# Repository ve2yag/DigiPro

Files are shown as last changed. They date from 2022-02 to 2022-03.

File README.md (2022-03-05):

# DigiPro
 Lora APRS digipeater for Arduino/AVR
 
 Atmega 168/328P(B) using internal 8MHz RC oscillator at 3.3 volts.
 
 - Support Lora carrier detect and collision avoiding using persistance and slottime, just like standard APRS
 - Compatible with ASCII packet format [LoRa-APRS-tracker](https://github.com/lora-aprs/LoRa_APRS_Tracker) and binary/AX25 format [sh123/esp32_loraprs](https://github.com/sh123/esp32_loraprs)
 - Digipeat packet in same format received. Digi beaconing and telemetry use the most heard format.
 - Digipeater support WIDEx-x and SSID digipeating for shortest packet.
 - Support ?APRS? and ?APRSS query
 - Support message ACKing, but don't use messaging for now. (remote config?)
 - Support 18650 battery voltage monitoring and sleep mode under 3.5 volts
 - Additional telemetry using DS18B20 and BMP180 for internal/external temperature and pressure.

Digipeater are extremly efficient, current draw is around 10,5ma on receive and 0,5ma when enter sleep mode. Only Lora module are powered and CPU stay in power down mode (few uA) Wake only when incoming packet is ready inside Lora module, also wake each second to check if it time to transmit beacon and telemetry. When all is tuned, I put some Goop glue on feedpoint connection to waterproof them.

Configure radio and digi with project.h file. 

[See schematic and PCB](Board.pdf)

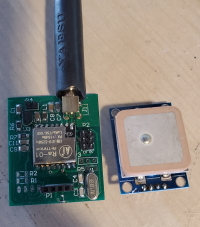
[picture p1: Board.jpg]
Board
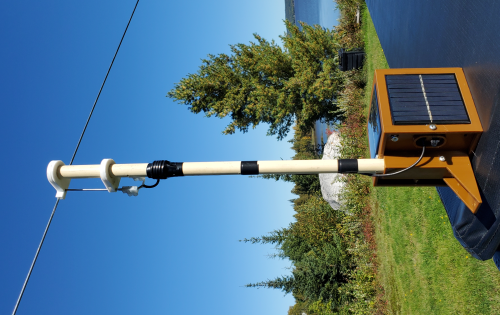
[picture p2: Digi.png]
Digi VA2AIG-4
  

Antenna is 3D printed EDZ, 2x 5/8 wave. 8.1dbi and easy to tune. Antenna is made from 36" stainless tig welding rod, 3/32 inch. Mast is 1/2 water CPVC pipe, coax RG-174/U. Coax coil at feed point is current balun to stabilize antenna pattern and choke current flow back to Lora module.

Enclosure is 3D printed, using Cubesat shape. Solar panel are 80mmx80mm 160ma@5v, 3 sides. (3D model in 3D_enclosure and antenna folder)

VA2AIG-4, Digipeater wide coverage (Have a bug with V2.0) [Map](https://fr.aprs.fi/#!call=a%2FVA2AIG-4&timerange=3600&tail=3600)
VE2YAG-4, Test digipeater, V2.1. Testing now at home, see telemetry.
[Telemetry](https://fr.aprs.fi/telemetry/a/VE2YAG-4) or see on [Map](https://fr.aprs.fi/info/a/VE2YAG-4)

I use also [MicroBeacon_2021](https://github.com/ve2yag/MicroBeacon_2021) as small testing tracker(same PCB) and Lorakiss as Kiss-over-IP Lora modem, hooked to APRX on a raspberry pi to create a dual-port igate with Direwolf.

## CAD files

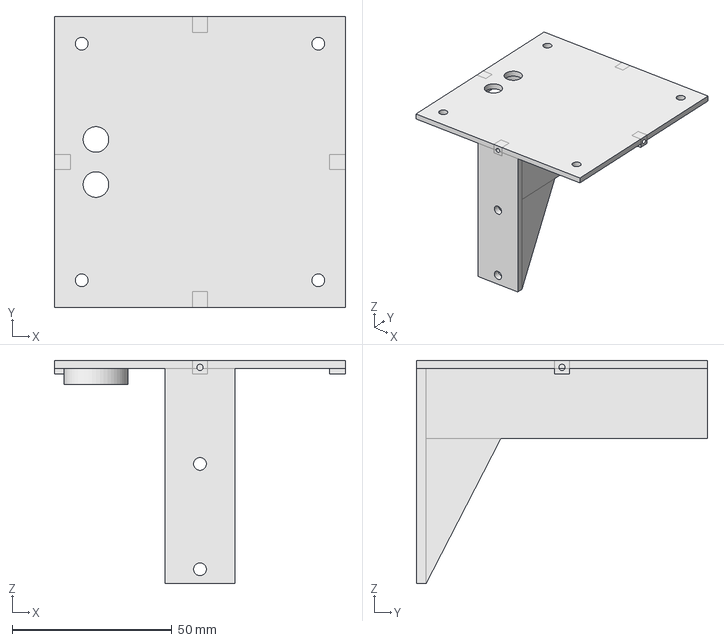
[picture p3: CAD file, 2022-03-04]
3D_enclosure/Base_RB_V1.2.FCStd
91.0 x 91.0 x 69.8 mm

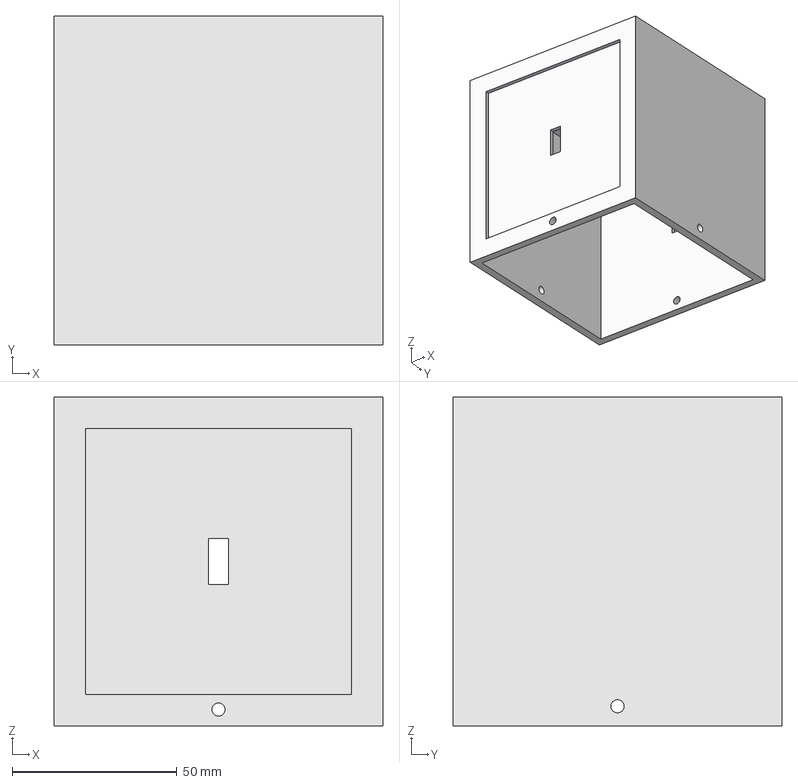
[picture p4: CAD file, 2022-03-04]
3D_enclosure/Cube_RB_V1.1.FCStd
100.0 x 100.0 x 100.0 mm

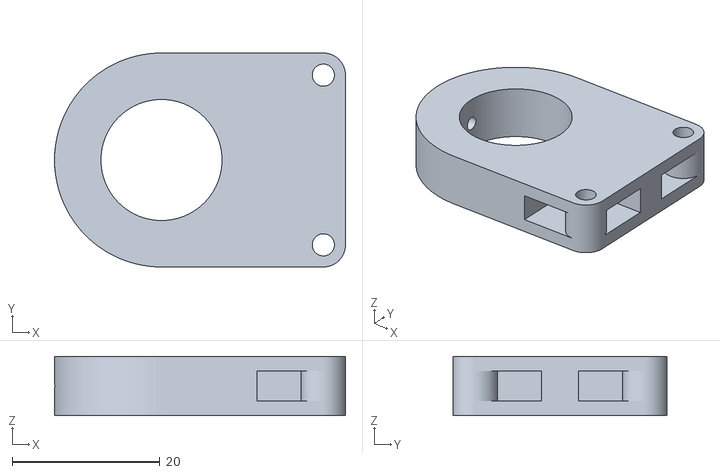
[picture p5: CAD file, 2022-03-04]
antenna/phasing mount-Body.stl
39.4 x 29.0 x 8.00

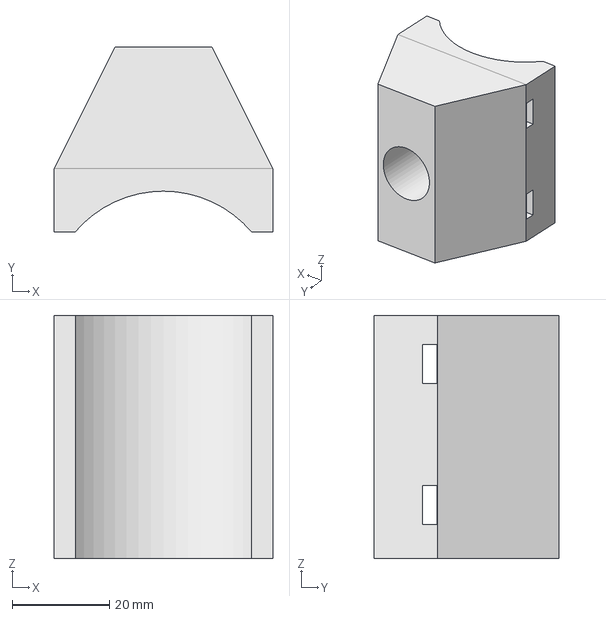
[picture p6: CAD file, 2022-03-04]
antenna/pole mount.FCStd
45.0 x 38.0 x 50.0 mm

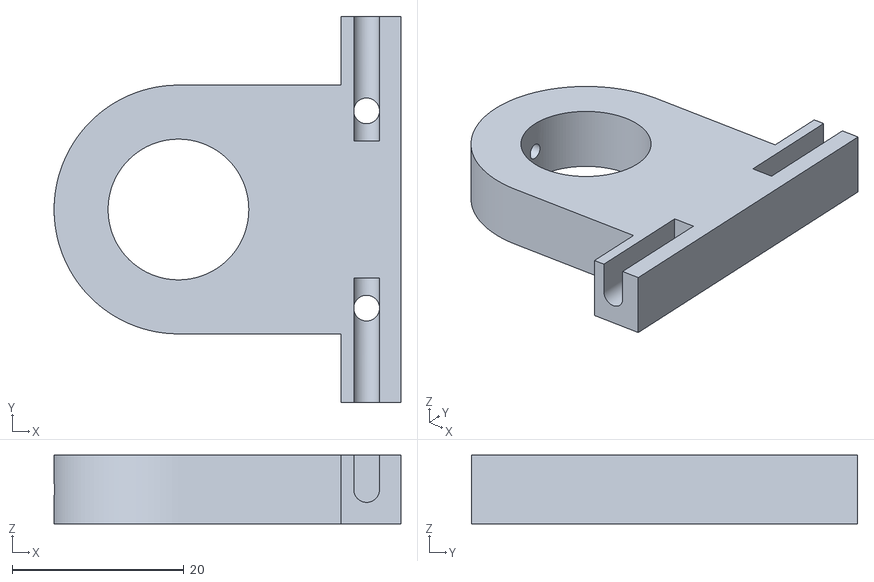
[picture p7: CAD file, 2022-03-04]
antenna/End mount V2-Body.stl
40.4 x 45.0 x 8.00

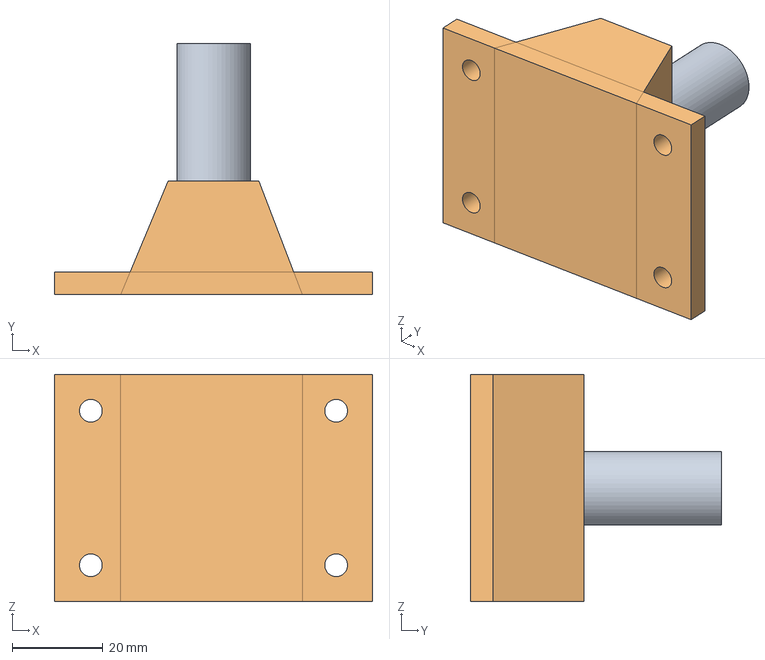
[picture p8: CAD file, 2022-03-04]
antenna/screw mount.FCStd
70.0 x 55.3 x 50.0 mm
hole body

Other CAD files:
3D_enclosure/Cube_RB_V1.1-Body.stl
3D_enclosure/Base_RB_V1.2-Body.stl
antenna/End mount V2.FCStd
antenna/phasing mount.FCStd
antenna/screw mount.stl

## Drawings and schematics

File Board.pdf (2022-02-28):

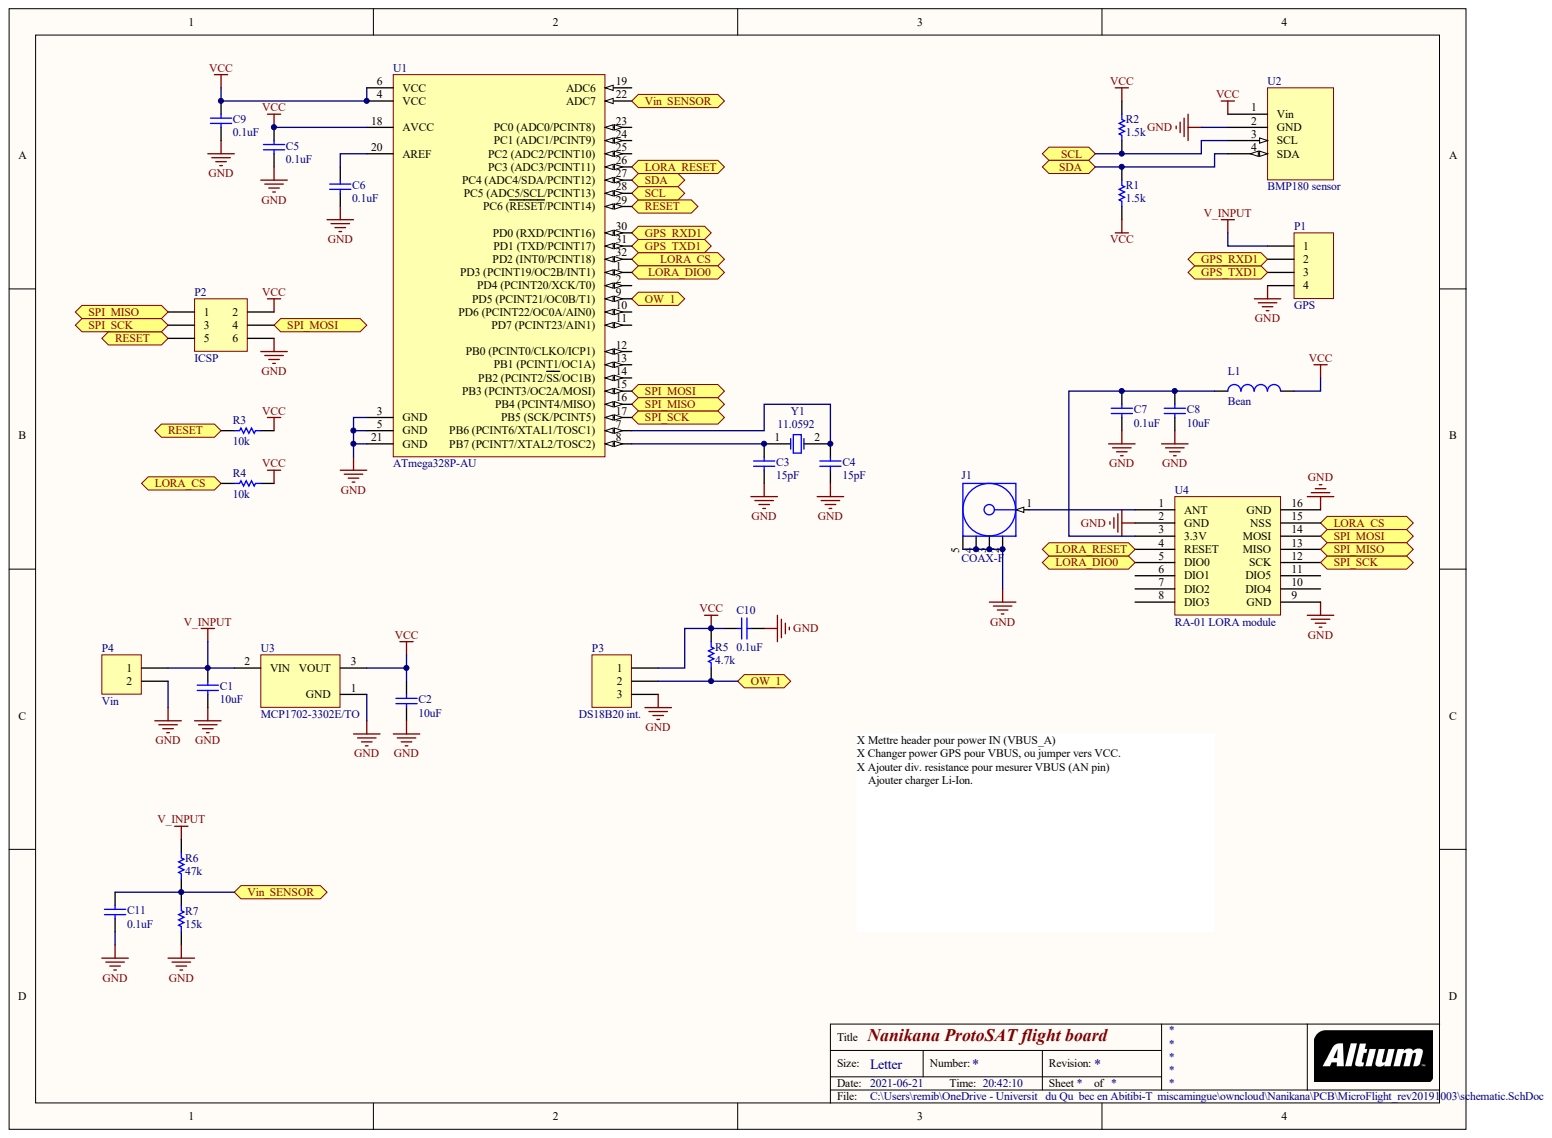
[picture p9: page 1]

X Mettre header pour power IN (VBUS_A)
X Changer power GPS pour VBUS, ou jumper vers VCC.
X Ajouter div. resistance pour mesurer VBUS (AN pin)
Ajouter charger Li-Ion.

Title Nanikana ProtoSAT flight board | * * * * *

Letter Size: | * Number: | * Revision:
Date: 2021-06-21 Time: 20:42:10 | | Sheet * of *

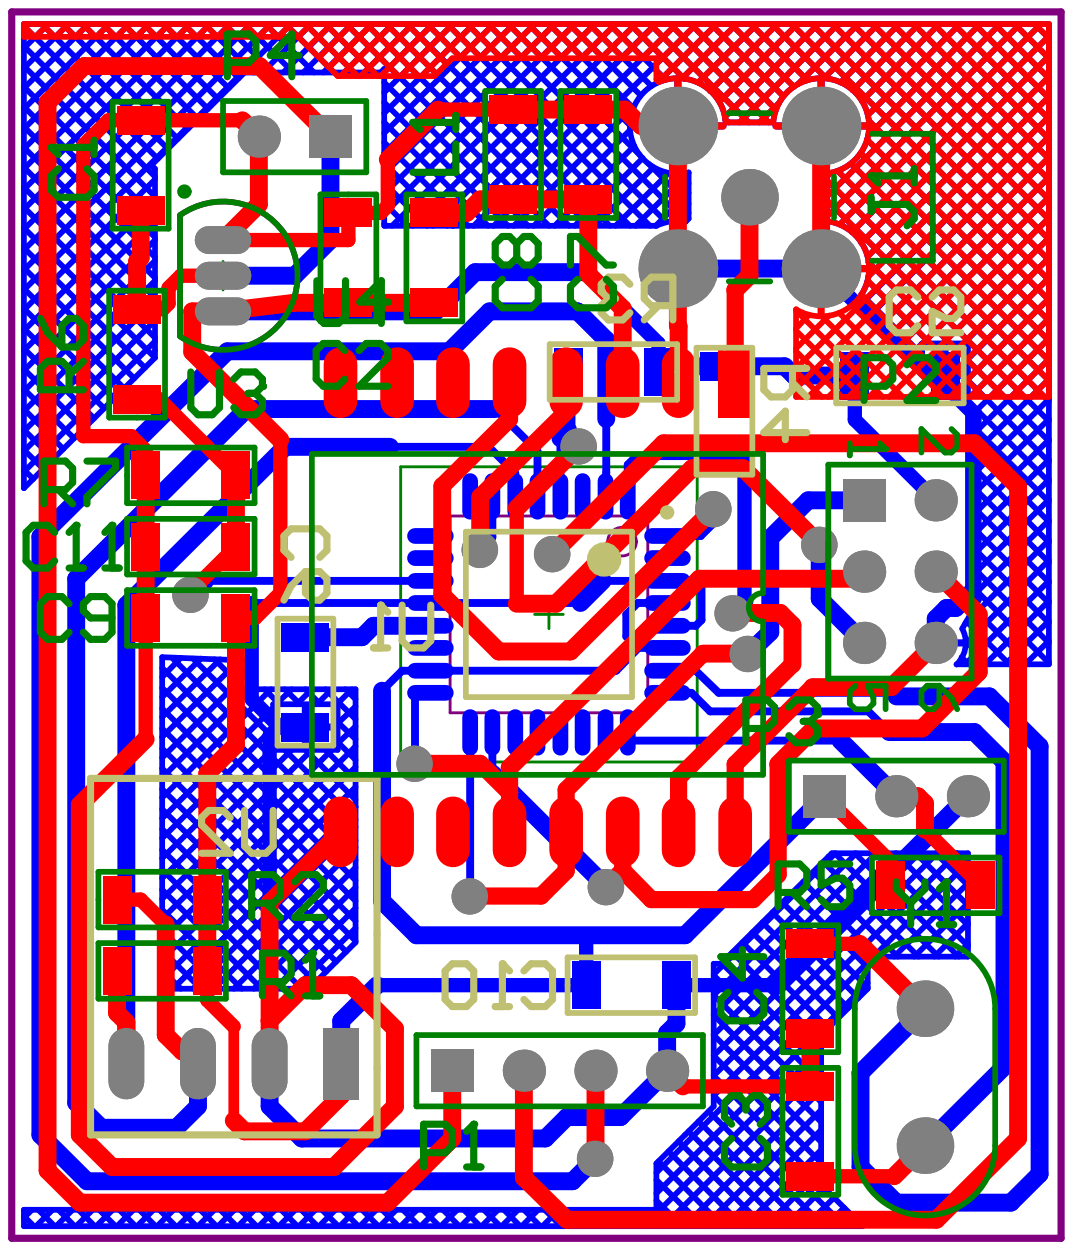
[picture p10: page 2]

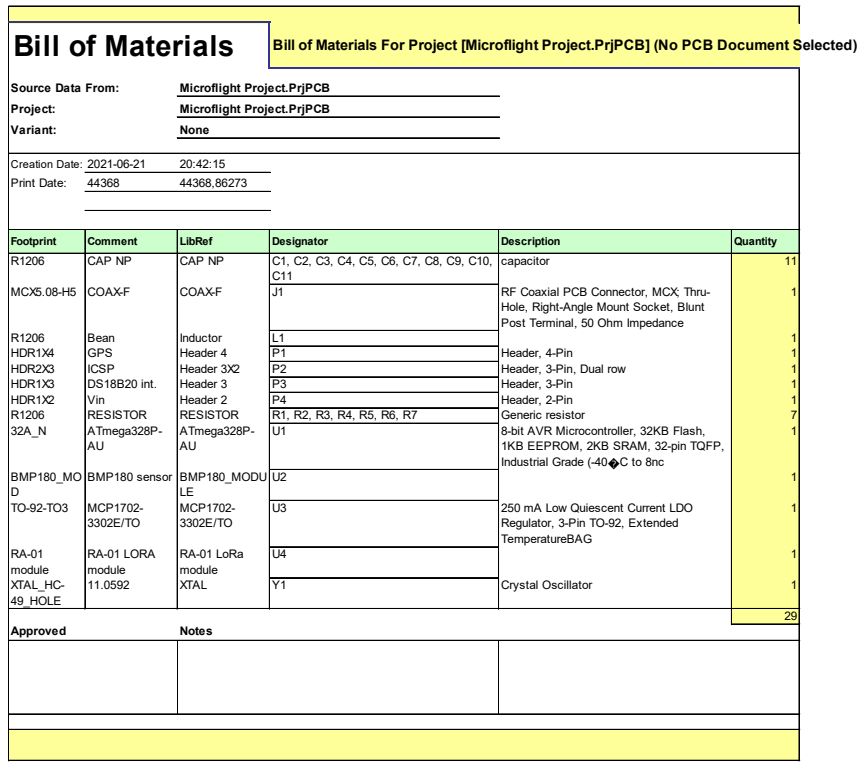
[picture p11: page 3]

Footprint | Comment | LibRef | Designator | Description | Quantity

Hole, Right-Angle Mount Socket, Blunt
Post Terminal, 50 Ohm Impedance

1KB EEPROM, 2KB SRAM, 32-pin TQFP,
Industrial Grade (-40C to 8nc

Regulator, 3-Pin TO-92, Extended
TemperatureBAG

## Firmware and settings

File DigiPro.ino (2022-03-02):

/***************************************************************************
 * Lora digipeater
 * 
 * Based on ExpressTracker code, using Lora module and Atmega 168/328 with
 * internal 8 MHz RC oscillator.
 * 
 * Note about using internal RC:
 * -Download MiniCore hardware lib for Arduino.
 * -Use Arduino as programmer and connect them to ICP header
 * -Configure Board with no bootloader, internal 8MHz and  hit burn bootloader 
 *  just to set configuration fuse. (default was RC internal 8/8 = 1 MHz.
 * -Burn code. Take note watchdog is enabled by default without bootloader, take care of them.
 * 
 * V1.0 - AIG-4 code, working good.
 * V2.0 - Code increase above 16k (328 only)
 *      - Added BMP180 sensor for internal temp and pressure
 *      - Re-organize code and file, adding watchdog,ax25_util and project.h
 *      - AIG-4 (sept. 2021)
 * V2.1 -BUG: Lora module ne reset jamais. Library laisse la pin non defini.
 *      -Retarder tout les beacons sauf 1 pour pas qu'il transmettre tous en même temps.
 *      -Compilation conditionnel pour enlever le BMP180 et le OE et compiler pour 168P (<16k)
 *      -BUG: When CPU reboot on transmit high current when battery are very cold, sleep 
 *       beacon is transmitted immediatly after each reboot and digi enter a death loop. 
 * 
 * Calibrate:
 * Batt voltage, using define in DigiPro.
 * RF Frequency, using SDR receiver and set frequency centered.
 * 
 * Pinout:
 * See project.h 
 * 
 * Current draw:
 * 11.83ma on RX (95% is lora Module), 0.63ma when radio module sleeping 
 * using MCP1702-33. Quiescent current of this regulator is 5uA max. Cheap
 * 1117 regulator quiescent current is around 10ma, more than whole circuit.
 * 
 * 
 ***************************************************************************/
#include <avr/sleep.h>
#include <OneWire.h> 
#include <DallasTemperature.h>
#include <Adafruit_BMP085.h>

#include "project.h"

/* TELEMETRY */
uint16_t batt_volt;
float ext_temp;
float int_temp,pressure;

bool sleep_flag;

/* EXTERIOR TEMPERATURE SENSOR */ 
#if DS_ENABLE==1
OneWire oneWire(DS_SENSOR); 
DallasTemperature sensors(&oneWire);
#endif

/* BMP180 INSIDE TEMPERATURE AND PRESSURE SENSOR */
#if BMP180_ENABLE==1
Adafruit_BMP085 bmp_sensor;
#endif


/******************************************
 * readVoltage()
 *****************************************/
#if VOLT_ENABLE==1
void readVoltage() {
	batt_volt = 0;
	for(uint8_t i=0; i<10; i++) batt_volt += analogRead(BATT_VOLT);
	batt_volt = (uint32_t)batt_volt * BAT_CAL / 10230L;
}
#endif

/******************************************
 * setup()
 *****************************************/
void setup() {

    /* CONFIGURE WATCHDOG FOR 1HZ INTERRUPT */
    Watchdog_setup();

    /* BATTERY VOLTAGE SENSOR */
    #if VOLT_ENABLE==1
    analogReference(INTERNAL);
    analogRead(BATT_VOLT);      // 1st reading seem a little bit off
	#endif
	
    /* IF MODEM CONFIGURE FAIL, RESET BOARD AT NEXT WATCHDOG IRQ */
    if(DigiInit() == 0) {
        wdt_flag = 31;
        while(1);       // Watchdog will reset
    }

    /* SENSOR INIT */ 
	#if DS_ENABLE==1
    sensors.begin();
	#endif
	#if BMP180_ENABLE==1
    bmp_sensor.begin();
	#endif
    #if VOLT_ENABLE==1
    readVoltage(); 
	#endif
}


/******************************************
 * loop()
 *****************************************/
void loop() {
    uint32_t t;
    static uint32_t sensor_to;

    /* GO TO SLEEP FOR 1 SECOND IF NO REQUEST FROM MODULE */
    if(digitalRead(LORA_DIO) == LOW) {

        /* ENABLE INTERRUPT ON DIO0 TO WAKE-UP FROM SLEEP */
        PCMSK2 = 0x08;    // PCINT19 pin-on-change interrupt for PD3
        PCICR = 0x04;     // PCINT2 ENABLE
    
        /* POWER DOWN CPU, WAKE-UP WITH 1Hz WATCHDOG INTERRUPT OR INCOMING PACKET */
        wdt_flag = 0;
        set_sleep_mode(SLEEP_MODE_PWR_DOWN);
        sleep_enable();
        sleep_mode();		// Watchdog wake CPU or DIO0 rising level, set in SX1278.CPP
        sleep_disable();

        /* DISABLE DIO0 INTERRUPT */
        PCICR = 0;
        PCMSK2 = 0;
    }

	/* CHECK SENSOR EACH MINUTE */
    if(wdt_clk > sensor_to) {
        sensor_to = wdt_clk + 60;

		/* AVERAGE 10x ADC READ BATTERY VOLTAGE IN mV */
		#if VOLT_ENABLE==1
		readVoltage();
		#endif
		
		/* DS18B20 EXTERIOR TEMP */
		#if DS_ENABLE==1
        sensors.requestTemperatures();  
        ext_temp = sensors.getTempCByIndex(0); 
		#endif
		
		/* BMP180 INTERIOR TEMP AND PRESSURE */
		#if BMP180_ENABLE==1
        pressure = (float)bmp_sensor.readPressure() / 1000.0;    // Measure in kPa;
        int_temp = bmp_sensor.readTemperature();        
		#endif
    }

    /* SEND AND RECEIVE PACKET, UNTIL NOTHING TO DO */
    while(DigiPoll());

    /* GO TO SLEEP MODE IF BATTERY DROP BELOW A LEVEL */
    #if VOLT_ENABLE==1
    if(batt_volt < 3500) {
		
		/* SEND SLEEP BEACON ONCE, AND ONLY IF CPU NOT REBOOTED ON LOW BATTERY ON TRANSMIT */
        if(sleep_flag==0 && wdt_clk>600) {
			lora.setPower(13);		// 20mW beacon 
			sleep_flag = 1;		
			DigiSendBeacon(2);    	// send system beacon for sleep mode
			lora.setPower(LORA_POWER);
		}        
        DigiSleep();          // Put lora radio module in sleep
        
        /* WAIT 15 MINUTES */
        t = wdt_clk + (60 * 15);
        while(wdt_clk < t) {
            wdt_flag = 0;
            set_sleep_mode(SLEEP_MODE_PWR_DOWN);
            sleep_enable();
            sleep_mode();
            sleep_disable();
        }
                
    } else sleep_flag = 0; 
	#endif
}

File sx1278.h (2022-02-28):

#ifndef _LORALIB_SX1278_H
#define _LORALIB_SX1278_H

#include <stdint.h>

//#define CS   2
//#define DIO0 3      // Make sure ISR is the good one. PCINT2 is for D0-D7 pin

#define ERR_NONE                        0x00
#define ERR_CHIP_NOT_FOUND              0x01

#define ERR_PACKET_TOO_LONG             0x10

#define ERR_RX_TIMEOUT                  0x20
#define ERR_CRC_MISMATCH                0x21
#define ERR_RX_EMPTY                    0x22

#define ERR_INVALID_BANDWIDTH           0x30
#define ERR_INVALID_SPREADING_FACTOR    0x31
#define ERR_INVALID_CODING_RATE         0x32

#define ERR_INVALID_BIT_RANGE           0x40

//enum Bandwidth {BW_7_80_KHZ, BW_10_40_KHZ, BW_15_60_KHZ, BW_20_80_KHZ, BW_31_25_KHZ, BW_41_70_KHZ, BW_62_50_KHZ, BW_125_00_KHZ, BW_250_00_KHZ, BW_500_00_KHZ };
//enum SpreadingFactor {SF_6, SF_7, SF_8, SF_9, SF_10, SF_11, SF_12};
//enum CodingRate {CR_4_5, CR_4_6, CR_4_7, CR_4_8};

//SX1278 register map
#define SX1278_REG_FIFO                               0x00
#define SX1278_REG_OP_MODE                            0x01
#define SX1278_REG_FRF_MSB                            0x06
#define SX1278_REG_FRF_MID                            0x07
#define SX1278_REG_FRF_LSB                            0x08
#define SX1278_REG_PA_CONFIG                          0x09
#define SX1278_REG_PA_RAMP                            0x0A
#define SX1278_REG_OCP                                0x0B
#define SX1278_REG_LNA                                0x0C
#define SX1278_REG_FIFO_ADDR_PTR                      0x0D
#define SX1278_REG_FIFO_TX_BASE_ADDR                  0x0E
#define SX1278_REG_FIFO_RX_BASE_ADDR                  0x0F
#define SX1278_REG_FIFO_RX_CURRENT_ADDR               0x10
#define SX1278_REG_IRQ_FLAGS_MASK                     0x11
#define SX1278_REG_IRQ_FLAGS                          0x12
#define SX1278_REG_RX_NB_BYTES                        0x13
#define SX1278_REG_RX_HEADER_CNT_VALUE_MSB            0x14
#define SX1278_REG_RX_HEADER_CNT_VALUE_LSB            0x15
#define SX1278_REG_RX_PACKET_CNT_VALUE_MSB            0x16
#define SX1278_REG_RX_PACKET_CNT_VALUE_LSB            0x17
#define SX1278_REG_MODEM_STAT                         0x18
#define SX1278_REG_PKT_SNR_VALUE                      0x19
#define SX1278_REG_PKT_RSSI_VALUE                     0x1A
#define SX1278_REG_RSSI_VALUE                         0x1B
#define SX1278_REG_HOP_CHANNEL                        0x1C
#define SX1278_REG_MODEM_CONFIG_1                     0x1D
#define SX1278_REG_MODEM_CONFIG_2                     0x1E
#define SX1278_REG_SYMB_TIMEOUT_LSB                   0x1F
#define SX1278_REG_PREAMBLE_MSB                       0x20
#define SX1278_REG_PREAMBLE_LSB                       0x21
#define SX1278_REG_PAYLOAD_LENGTH                     0x22
#define SX1278_REG_MAX_PAYLOAD_LENGTH                 0x23
#define SX1278_REG_HOP_PERIOD                         0x24
#define SX1278_REG_FIFO_RX_BYTE_ADDR                  0x25
#define SX1278_REG_MODEM_CONFIG_3                     0x26
#define SX1278_REG_PPMCORRECTION                      0x27
#define SX1278_REG_FEI_MSB                            0x28
#define SX1278_REG_FEI_MID                            0x29
#define SX1278_REG_FEI_LSB                            0x2A
#define SX1278_REG_RSSI_WIDEBAND                      0x2C
#define SX1278_REG_DETECT_OPTIMIZE                    0x31
#define SX1278_REG_INVERT_IQ                          0x33
#define SX1278_REG_DETECTION_THRESHOLD                0x37
#define SX1278_REG_SYNC_WORD                          0x39
#define SX1278_REG_DIO_MAPPING_1                      0x40
#define SX1278_REG_DIO_MAPPING_2                      0x41
#define SX1278_REG_VERSION                            0x42
#define SX1278_REG_TCXO                               0x4B
#define SX1278_REG_PA_DAC                             0x4D
#define SX1278_REG_FORMER_TEMP                        0x5D
#define SX1278_REG_AGC_REF                            0x61
#define SX1278_REG_AGC_THRESH_1                       0x62
#define SX1278_REG_AGC_THRESH_2                       0x63
#define SX1278_REG_AGC_THRESH_3                       0x64
#define SX1278_REG_PLL                                0x70

//SX1278 LoRa modem settings
//SX1278_REG_OP_MODE                                                  MSB   LSB   DESCRIPTION
#define SX1278_FSK_OOK                                0b00000000  //  7     7     FSK/OOK mode
#define SX1278_LORA                                   0b10000000  //  7     7     LoRa mode
#define SX1278_ACCESS_SHARED_REG_OFF                  0b00000000  //  6     6     access LoRa registers (0x0D:0x3F) in LoRa mode
#define SX1278_ACCESS_SHARED_REG_ON                   0b01000000  //  6     6     access FSK registers (0x0D:0x3F) in LoRa mode
#define SX1278_HIGH_FREQ                              0b00000000  //  3     3     access HF test registers
#define SX1278_LOW_FREQ                               0b00001000  //  3     3     access LF test registers
#define SX1278_SLEEP                                  0b00000000  //  2     0     sleep
#define SX1278_STANDBY                                0b00000001  //  2     0     standby
#define SX1278_FSTX                                   0b00000010  //  2     0     frequency synthesis TX
#define SX1278_TX                                     0b00000011  //  2     0     transmit
#define SX1278_FSRX                                   0b00000100  //  2     0     frequency synthesis RX
#define SX1278_RXCONTINUOUS                           0b00000101  //  2     0     receive continuous
#define SX1278_RXSINGLE                               0b00000110  //  2     0     receive single
#define SX1278_CAD                                    0b00000111  //  2     0     channel activity detection

//SX1278_REG_FRF_MSB + REG_FRF_MID + REG_FRF_LSB 434.000Mhz
//#define SX1278_FRF_MSB                                0x6C        //  7     0     carrier frequency setting: f_RF = (F(XOSC) * FRF)/2^19
//#define SX1278_FRF_MID                                0x80        //  7     0         where F(XOSC) = 32 MHz
//#define SX1278_FRF_LSB                                0x00        //  7     0               FRF = 3 byte value of FRF registers

// FRF = 7139328(0x6CF000) for 435.750
//#define SX1278_FRF_MSB                                0x6C        //  7     0     carrier frequency setting: f_RF = (F(XOSC) * FRF)/2^19
//#define SX1278_FRF_MID                                0xF0        //  7     0         where F(XOSC) = 32 MHz
//#define SX1278_FRF_LSB                                0x00        //  7     0               FRF = 3 byte value of FRF registers
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

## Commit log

2022-03-01 More config switch in project.h
2022-03-04 Add antenna and enclosure
    [Base_RB_V1.2-Body.stl, Base_RB_V1.2.FCStd, Cube_RB_V1.1-Body.stl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]
